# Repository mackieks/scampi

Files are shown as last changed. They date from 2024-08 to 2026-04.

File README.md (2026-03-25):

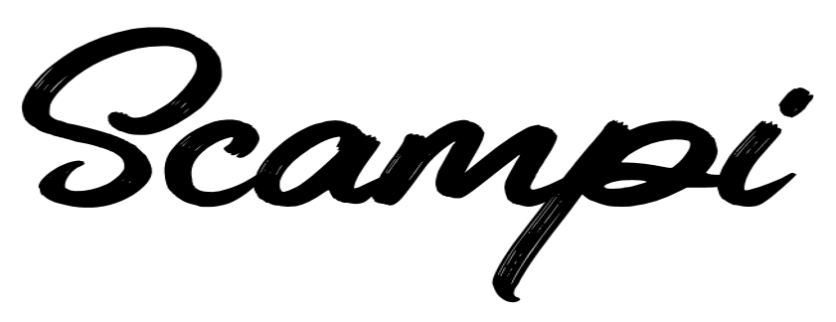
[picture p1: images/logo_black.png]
<picture> <source media="(prefers-color-scheme: dark)" srcset="images/logo.png">  </picture> 

Scampi is a truly universal OSHW audio amp for portablizers. Hardware design is tested and working. Firmware is nearly complete.

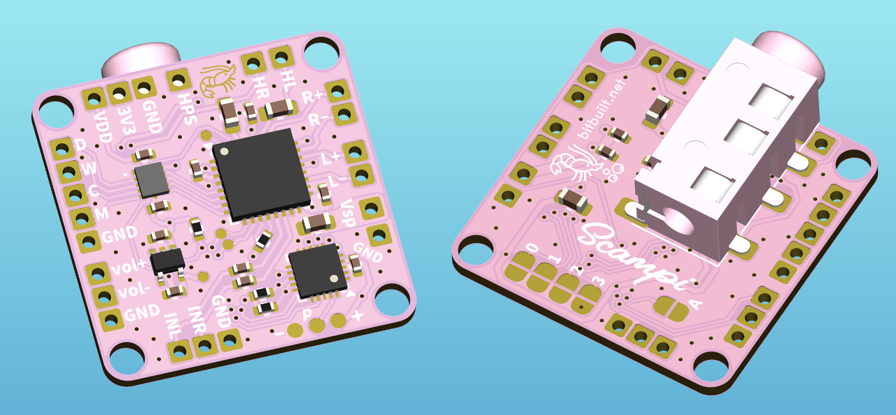
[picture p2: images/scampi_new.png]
 

Features:

- Low-cost 20x20mm 2-layer PCB
- TLV320AIC3110 codec with stereo 1.3W Class-D amps and Class-AB headphone driver
- 5V-tolerant level-shifted I2S input + analog input
- Onboard switching 3.5mm headphone jack
- Solder jumpers for mode selection (15 modes planned)
- Shrimp-themed!🦐
  
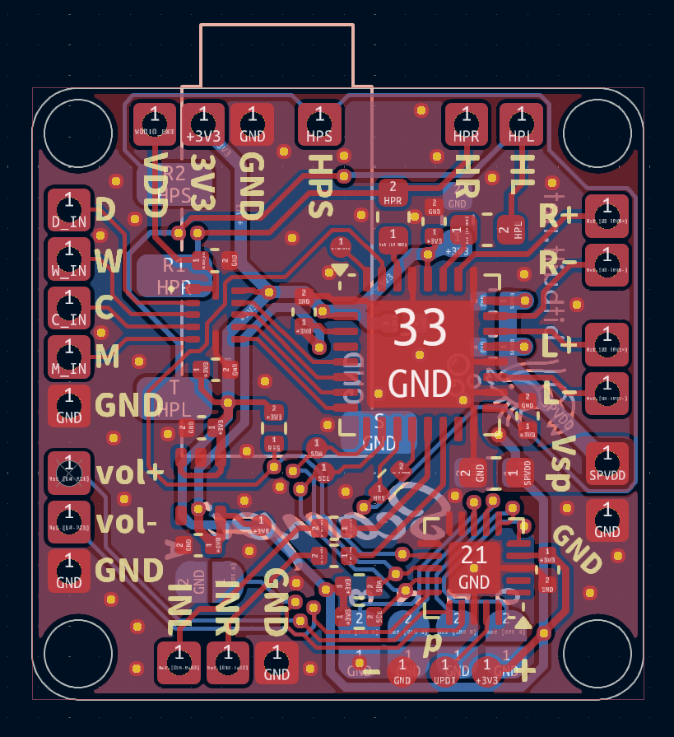
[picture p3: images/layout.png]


Recommended speakers: [Nintendo Switch 2 speakers](https://www.aliexpress.us/item/3256809887996046.html)

Headphone jack (remove pegs with flush cutters): [PJ320D](https://www.aliexpress.us/item/3256808202284065.html)

Hardware tested and working! Firmware is nearly complete! Supported modes so far:

- [x] Analog input
- [x] SNES
- [x] N64
- [x] GameCube
- [x] Wii
- [x] Wii U
- [ ] PS1
- [ ] PS2
- [ ] PS3
- [x] Saturn
- [x] Dreamcast
- [ ] XBOX
- [ ] Xbox 360
- [ ] Jaguar
- [ ] Neo Geo

## License
Solderpad Hardware License v2.1

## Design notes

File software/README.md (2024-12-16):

# Scampi Firmware

Pre-built binaries for the firmware can be found in the [releases](https://github.com/mackieks/scampi/releases) section.

## Firmware

The Scampi firmware is written in AVR C with no external dependencies. It uses [PlatformIO](https://platformio.org/) to build and flash the firmware, providing a consistent build environment and an easy way to manage toolchains.

### Prerequisites

- [PlatformIO IDE](https://platformio.org/install/ide?install=vscode) for VS Code
- UPDI programmer (e.g., [ATMEL-ICE](https://www.microchip.com/en-us/development-tool/atatmel-ice), [Adafruit UPDI Friend](https://www.adafruit.com/product/5879), [SerialUPDI](https://www.tindie.com/products/mcudude/serialupdi-programmer/)).

### Building

To build the firmware in VS Code, open the `firmware` folder in VS Code, and let the PlatformIO extension configure the project. Then click the Build button at the bottom (check mark icon).

### Flashing

Flashing the firmware requires a UPDI programmer. You can use the official [ATMEL-ICE](https://www.microchip.com/en-us/development-tool/atatmel-ice), or a cheaper programmer such as the [Adafruit UPDI Friend](https://www.adafruit.com/product/5879) or MCUdude's [SerialUPDI](https://www.tindie.com/products/mcudude/serialupdi-programmer/).

You need to change line 8 of `platformio.ini` to match the programmer you're using.

- `atmelice_updi` for ATMEL-ICE
- `serialupdi` for SerialUPDI or UPDI Friend

See [this page](https://github.com/SpenceKonde/megaTinyCore/blob/master/megaavr/extras/PlatformIO.md#upload_protocol) for a full list of config options.

The Scampi PCB must be powered from the 3.3V and GND pads for programming to succeed! 

In VS Code, click the Upload button (arrow icon) to flash the firmware. Ensure your UPDI programmer is connected before clicking the button!

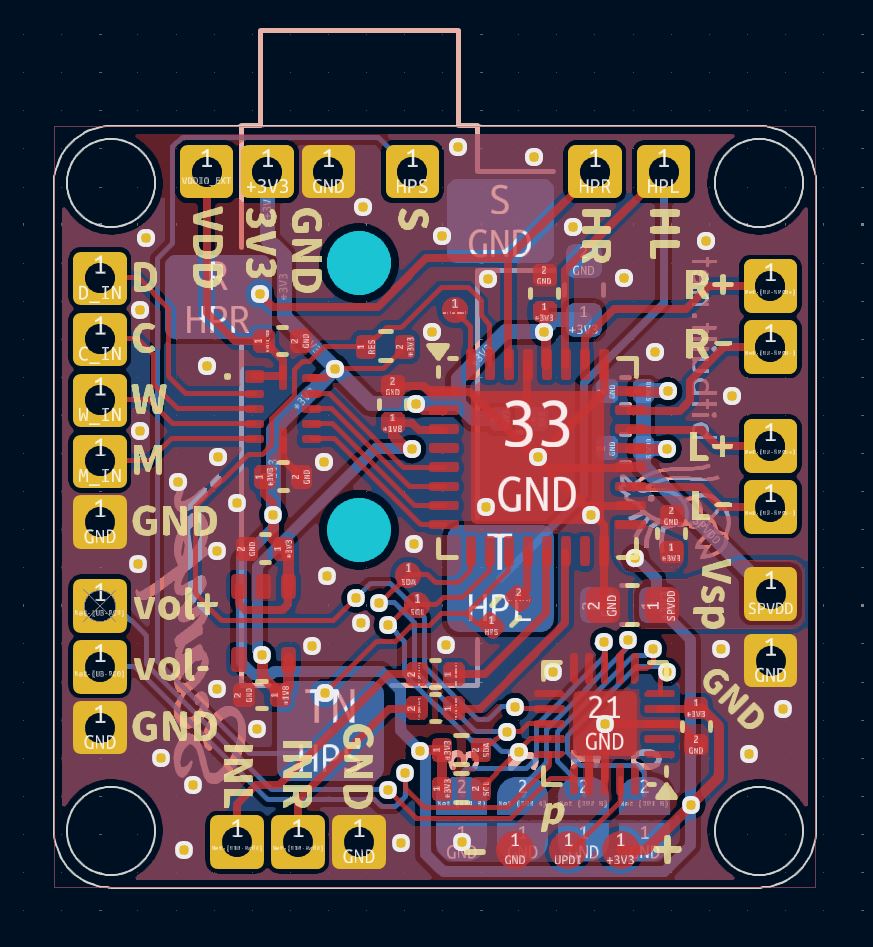
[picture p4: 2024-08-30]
images/layout.jpg

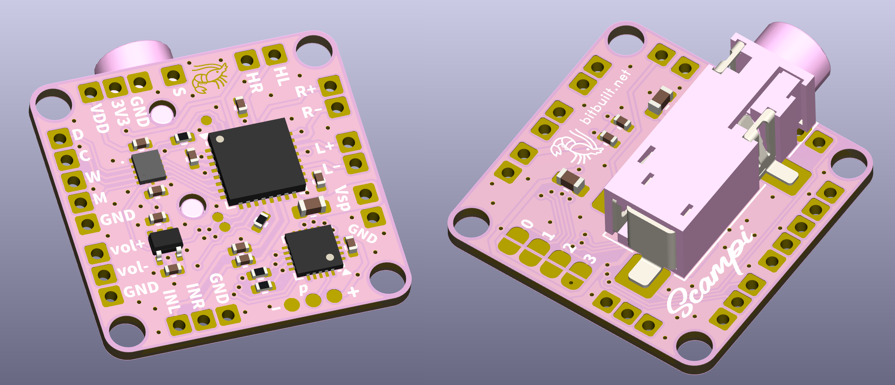
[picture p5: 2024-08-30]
images/scampi.png

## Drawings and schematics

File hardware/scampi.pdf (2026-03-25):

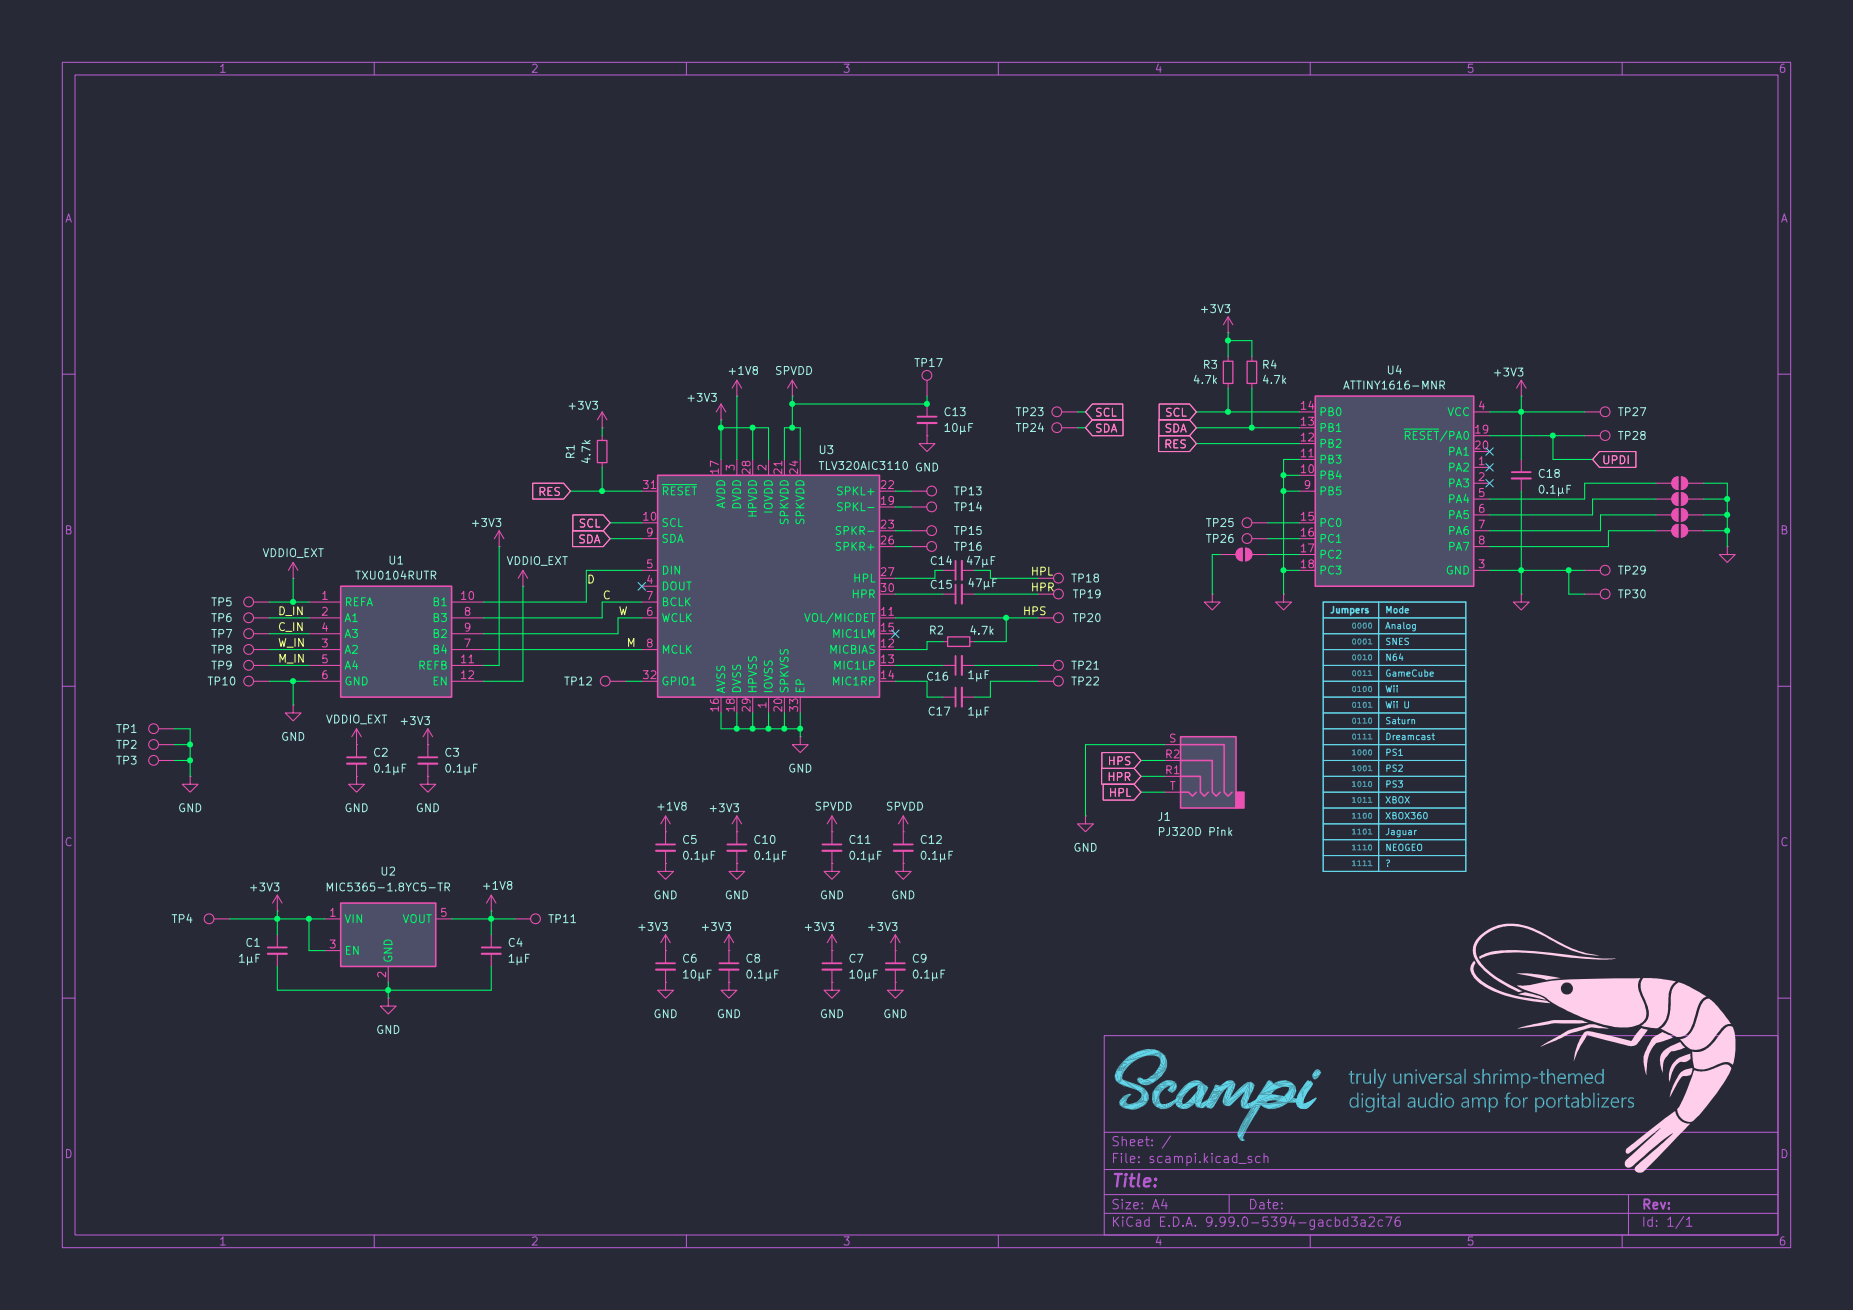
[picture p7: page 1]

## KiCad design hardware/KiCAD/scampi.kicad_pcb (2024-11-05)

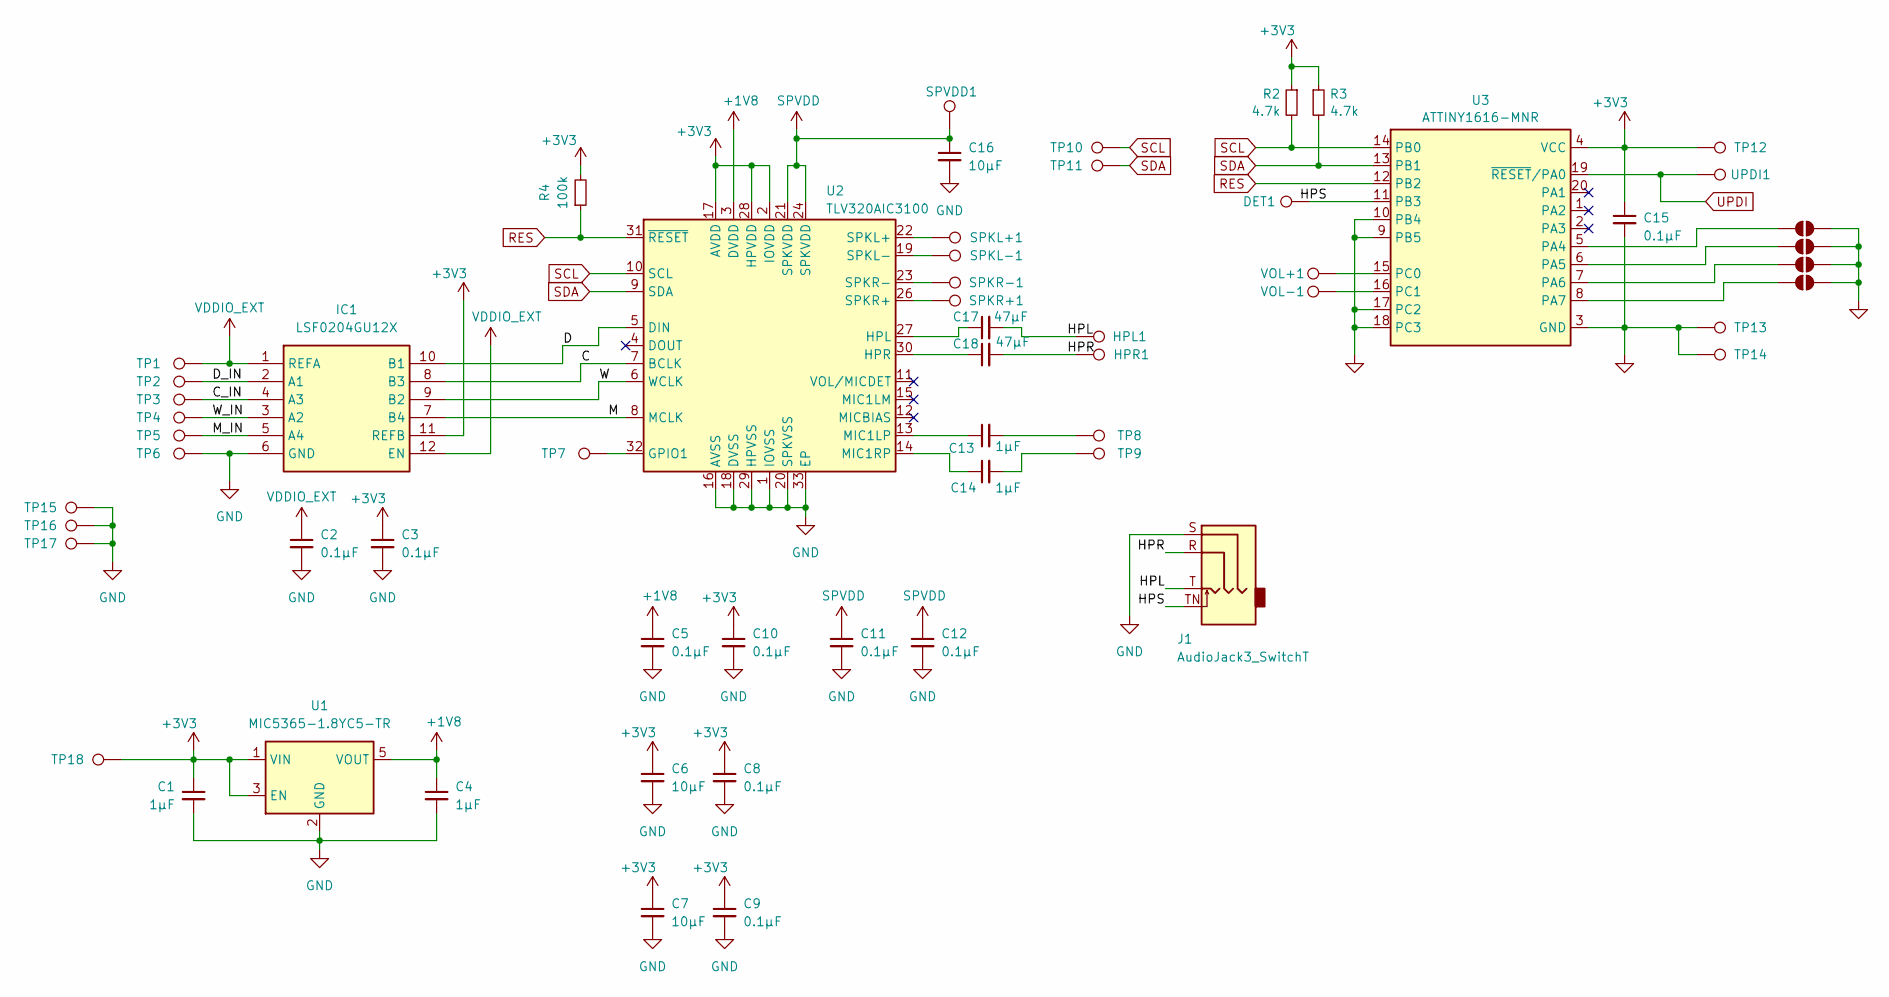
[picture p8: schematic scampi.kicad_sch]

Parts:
C1, C4, C13, C14: 1µF; C_0402_1005Metric
C2, C3, C5, C8, C9, C10, C11, C12, C15: 0.1µF; C_0402_1005Metric
C6, C7, C16: 10µF; C_0603_1608Metric
C17, C18: 47µF; C_0603_1608Metric
DET1: pth_pad
HPL1: pth_pad
HPR1: pth_pad
IC1: LSF0204GU12X; Mouser Part Number 771-LSF0204GU12X
J1: AudioJack3_SwitchT; Jack_3.5mm_CUI_SJ-3524-SMT_Horizontal
JP1, JP2, JP3, JP4: SolderJumper_2_Open; small_solder_jumper
R2, R3: 4.7k; R_0402_1005Metric
R4: 100k; R_0402_1005Metric
SPKL+1: pth_pad
SPKL-1: pth_pad
SPKR+1: pth_pad
SPKR-1: pth_pad
SPVDD1: pth_pad
TP1, TP2, TP3, TP4, TP5, TP6, TP8, TP9, TP15, TP16, TP17, TP18: pth_pad
TP7: TestPoint_Pad_D1.0mm
TP10: SCL; TestPoint_Pad_D1.0mm
TP11: SDA; TestPoint_Pad_D1.0mm
TP12: V+; TestPoint_Pad_D1.0mm
TP13: GND; pth_pad
TP14: GND; TestPoint_Pad_D1.0mm
U1: MIC5365-1.8YC5-TR; SOT-353_SC-70-5
U2: TLV320AIC3100; VQFN-32-1EP_5x5mm_P0.5mm_EP3.5x3.5mm
U3: ATTINY1616-MNR; VQFN-20-1EP_3x3mm_P0.4mm_EP1.7x1.7mm
UPDI1: UPDI; TestPoint_Pad_D1.0mm
VOL+1: pth_pad
VOL-1: pth_pad

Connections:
+1V8: C4.1, C5.1, U1.5 (VOUT), U2.3 (DVDD)
+3V3: C1.1, C3.1, C6.1, C7.1, C8.1, C9.1, C10.1, C15.1, IC1.11 (REFB), R2.1, R3.1, R4.2, TP12.1, TP18.1, U1.1 (VIN), U1.3 (EN), U2.2 (IOVDD), U2.17 (AVDD), U2.28 (HPVDD), U3.4 (VCC)
/C: IC1.8 (B3), U2.7 (BCLK)
/C_IN: IC1.4 (A3), TP3.1
/D: IC1.10 (B1), U2.5 (DIN)
/D_IN: IC1.2 (A1), TP2.1
/HPL: C17.2, HPL1.1, J1.T
/HPR: C18.2, HPR1.1, J1.R
/HPS: DET1.1, J1.TN, U3.11 (PB3)
/M: IC1.7 (B4), U2.8 (MCLK)
/M_IN: IC1.5 (A4), TP5.1
/W: IC1.9 (B2), U2.6 (WCLK)
/W_IN: IC1.3 (A2), TP4.1
GND: C1.2, C2.2, C3.2, C4.2, C5.2, C6.2, C7.2, C8.2, C9.2, C10.2, C11.2, C12.2, C15.2, C16.2, IC1.6 (GND), J1.S, JP1.1 (A), JP2.1 (A), JP3.1 (A), JP4.1 (A), TP6.1, TP13.1, TP14.1, TP15.1, TP16.1, TP17.1, U1.2 (GND), U2.1 (IOVSS), U2.16 (AVSS), U2.18 (DVSS), U2.20 (SPKVSS), U2.25 (SPKVSS), U2.29 (HPVSS), U2.33 (EP), U3.3 (GND), U3.9 (PB5), U3.10 (PB4), U3.17 (PC2), U3.18 (PC3), U3.21 (GND)
unnamed: C13.2, TP8.1
unnamed: C14.2, TP9.1
unnamed: JP1.2 (B), U3.5 (PA4)
unnamed: JP2.2 (B), U3.6 (PA5)
unnamed: JP3.2 (B), U3.7 (PA6)
unnamed: JP4.2 (B), U3.8 (PA7)
unnamed: TP7.1, U2.32 (GPIO1)
unnamed: C17.1, U2.27 (HPL)
unnamed: C18.1, U2.30 (HPR)
unnamed: C13.1, U2.13 (MIC1LP)
unnamed: C14.1, U2.14 (MIC1RP)
unnamed: SPKL+1.1, U2.22 (SPKL+)
unnamed: SPKL-1.1, U2.19 (SPKL-)
unnamed: SPKR+1.1, U2.26 (SPKR+)
unnamed: SPKR-1.1, U2.23 (SPKR-)
unnamed: U3.15 (PC0), VOL+1.1
unnamed: U3.16 (PC1), VOL-1.1
RES: R4.1, U2.31 (~RESET), U3.12 (PB2)
SCL: R2.2, TP10.1, U2.10 (SCL), U3.14 (PB0)
SDA: R3.2, TP11.1, U2.9 (SDA), U3.13 (PB1)
SPVDD: C11.1, C12.1, C16.1, SPVDD1.1, U2.21 (SPKVDD), U2.24 (SPKVDD)
UPDI: U3.19 (~RESET/PA0), UPDI1.1
VDDIO_EXT: C2.1, IC1.1 (REFA), IC1.12 (EN), TP1.1

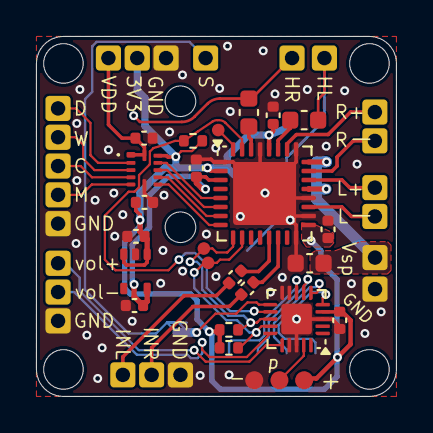
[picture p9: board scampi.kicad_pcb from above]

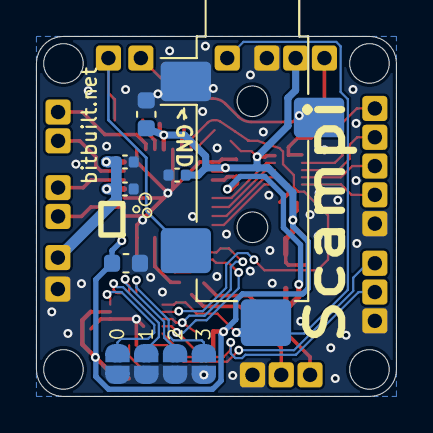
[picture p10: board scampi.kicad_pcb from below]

Board: 2 copper layers, 20.0 x 20.0 mm, 59 parts (10 on the bottom side), 37 nets.

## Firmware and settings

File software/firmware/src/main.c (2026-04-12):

/*
  Scampi firmware

  Application code for ATtiny1616 and TLV320AIC3110

  https://www.ti.com/lit/ds/symlink/tlv320aic3110.pdf

  Mackie Kannard-Smith, James Smith 2024
  MIT License

*/

#include <stdint.h>
#include <string.h>

#include <avr/eeprom.h>
#include <avr/interrupt.h>
#include <avr/io.h>
#include <util/delay.h>

#include "gpio.h"
#include "i2c.h"
#include "i2c/tlv320aic3110.h"

// old PCB has A_MODE tied to GND.
#define FORCE_AMODE 0

// speaker type (controls gain)
#define IPHONE_15PM 0
#define SWITCH_2 1
#define CMS_151135 0
#define FOUR_OHM_20MM 0

// set this to 1 to change the volume pot rotation direction
#define INVERT_VOL_POT 0

// RTC millisecond counter
static volatile uint32_t millis = 0;

static volatile uint8_t mode = 0;

// set this to the min and max ADC readings you get from your volume pot
// for example, if Vmin = 100mV, (0.100 / 3.3) * 1024 = 31
static volatile uint8_t VOL_POT_MIN    = 128; // real value comes from eeprom
static volatile uint8_t VOL_POT_MAX    = 128; // real value comes from eeprom
static volatile uint8_t MUTE_THRESHOLD = 1; // Adjustable threshold above/below POT_MIN/POT_MAX to mute at

static volatile bool analog_vol_ctrl   = 0;
static volatile bool headset_connected = 0;
static volatile bool mute              = 0;
static volatile bool vol_down_pressed  = 0;
static volatile bool vol_up_pressed    = 0;

// higher value = reduced gain (see Table 7-38 in datasheet)
static const uint8_t min_vol = 50;
static const uint8_t max_vol = 0;

#if IPHONE_15PM
static const uint8_t spk_gain = 0x0; // +24dB
#elif SWITCH_2
static const uint8_t spk_gain = 0x0; // +20dB
#elif CMS_151135
static const uint8_t spk_gain = 0x20; // +16dB
#elif FOUR_OHM_20MM
static const uint8_t spk_gain = 0x28; // +20dB
#endif

static const uint8_t hp_gain = 0x00; // 0dB (suitable for my 15Ω headphones)

static volatile uint8_t vol     = 0;
static volatile uint8_t spk_vol = 0;
static volatile uint8_t hp_vol  = 0;

static volatile uint8_t vol_pot = 0; // analog volume pot reading (0 - 255)

// GPIO pin definitions
static const gpio_t RESET  = {&PORTB, 2}; // PB2
static const gpio_t VOL_UP = {&PORTC, 1}; // PC1
static const gpio_t VOL_DN = {&PORTC, 0}; // PC0
static const gpio_t A_MODE = {&PORTC, 2}; // PC2 (analog vol ctrl mode)

static const gpio_t MODE0 = {&PORTA, 4}; // PA4
static const gpio_t MODE1 = {&PORTA, 5}; // PA5
static const gpio_t MODE2 = {&PORTA, 6}; // PA6
static const gpio_t MODE3 = {&PORTA, 7}; // PA7

// Initialize the RTC for periodic interrupts
void rtc_init()
{
  RTC.CLKSEL     = RTC_CLKSEL_INT32K_gc;
  RTC.PITINTCTRL = RTC_PI_bm;
  RTC.PITCTRLA   = RTC_PERIOD_CYC32_gc | RTC_PITEN_bm;
}

// Handle periodic RTC interrupts (every ~1ms)
ISR(RTC_PIT_vect)
{
  // Clear the interrupt flag
  RTC.PITINTFLAGS = RTC_PI_bm;

  // Update the "milliseconds since boot" counter
  millis++;
}

// Force reset eeprom for debug
static void reset_eeprom()
{
  // Write the default pot min and max values
  eeprom_write_byte(0x00, 0x80); // VOL_POT_MIN
  eeprom_write_byte(0x01, 0x80); // VOL_POT_MAX
}

// Initialize the EEPROM if it has never been initialized
static void eeprom_init()
{
  // Return early if the EEPROM has already been initialized
  if (eeprom_read_word(0xFE) == 0xCAFE)
    return;

  // Write the default pot min and max values
  eeprom_write_byte(0x00, 0x80); // VOL_POT_MIN
  eeprom_write_byte(0x01, 0x80); // VOL_POT_MAX

  // Write the signature
  eeprom_write_word(0xFE, 0xCAFE);
}

// Initialize the GPIO pins
static void gpio_init()
{
  // Codec reset, active low
  gpio_output(RESET);
  gpio_set_low(RESET);

  gpio_input(VOL_DN);
  gpio_input(A_MODE);
  gpio_input(MODE0);
  gpio_input(MODE1);
  gpio_input(MODE2);
  gpio_input(MODE3);

  // internal pullups for IO pins

  gpio_pullup(A_MODE);
  gpio_pullup(MODE0);
  gpio_pullup(MODE1);
  gpio_pullup(MODE2);
  gpio_pullup(MODE3);

  if (FORCE_AMODE ? true : !gpio_read(A_MODE)) { // enable analog volume control mode

    analog_vol_ctrl = true;

    // ADC1 on VOL_DN (PC0)
    ADC1.CTRLA   = 0x07; // enable ADC in free-running 8-bit mode
    ADC1.CTRLC   = 0x01010011; // reduced capacitance mode, set VREF to VDD, div16 prescaler
    ADC1.MUXPOS  = ADC_MUXPOS_AIN6_gc; // select PC0
    ADC1.COMMAND = 0b1; // start conversion

    gpio_output(VOL_UP); // use VOL_UP to power the volume pot
    gpio_set_high(VOL_UP);

    // grab VOL_POT_MIN and VOL_POT_MAX from EEPROM
    VOL_POT_MIN = eeprom_read_byte(0x00);
    VOL_POT_MAX = eeprom_read_byte(0x01);

  } else {
    gpio_input(VOL_UP); // use VOL_UP for a button
    gpio_pullup(VOL_UP);
    gpio_pullup(VOL_DN);
  }
}

static uint8_t mode_detect()
{

  mode |= !gpio_read(MODE0);
  mode |= !gpio_read(MODE1) << 1;
  mode |= !gpio_read(MODE2) << 2;
  mode |= !gpio_read(MODE3) << 3;

  return (mode);
}

static void codec_write(int reg, int value)
{ i2c_reg_write_byte(TLV320_ADDR, reg, value); }

volatile int codec_read(int reg)
{
  int data;
  i2c_reg_read_byte(TLV320_ADDR, reg, &data);
  return (data);
}

static void codec_reset()
{
  // Reset codec
  gpio_set_low(RESET);
  _delay_ms(10);
  gpio_set_high(RESET);
}

static void set_dac_gain(uint8_t gain)
{
  // digital gain
  codec_write(0x00, 0x00); // select page 0
  codec_write(0x41, gain); // DAC -> +24dB gain left
  codec_write(0x42, gain); // DAC -> +24dB gain right
}

static void set_spk_vol(uint8_t vol)
{
  codec_write(0x00, 0x01); // Select page 1
  codec_write(0x26, spk_vol); // SPL analog volume
  codec_write(0x27, spk_vol); // SPR analog volume
}

static void set_hp_vol(uint8_t vol)
{
  codec_write(0x00, 0x01); // Select page 1
  codec_write(0x24, hp_vol); // HPL analog volume
  codec_write(0x25, hp_vol); // HPR analog volumee
}

static void mute_spk()
{
  codec_write(0x00, 0x01); // Select page 1
  codec_write(0x2A, 0x00); // SPL driver mute
  codec_write(0x2B, 0x00); // SPR driver mute
  // codec_write(0x20, 0x06); // power down class D drivers
}

static void mute_hp()
{
  codec_write(0x00, 0x01); // Select page 1
  codec_write(0x28, 0x02); // HPL driver mute
  codec_write(0x29, 0x02); // HPR driver mute
  // codec_write(0x1F, 0x04); // power down headphone drivers
}

static void unmute_spk()
{
  codec_write(0x00, 0x01); // Select page 1
  codec_write(0x20, 0xC6); // power up class D drivers

  if (mode == 0) { // analog input mode needs higher SPx driver gain
    codec_write(0x2A, 0b00011100); // SPL driver unmute, +24dB gain
    codec_write(0x2B, 0b00011100); // SPR driver unmute, +24dB gain
  } else { // digital input modes use digital volume control
    codec_write(0x2A, 0b00011100); // SPL driver unmute, +6dB gain
    codec_write(0x2B, 0b00011100); // SPR driver unmute, +6dB gain
  }
}

static void unmute_hp()
{
  codec_write(0x00, 0x01); // Select page 1
  codec_write(0x1F, 0xC4); // power up headphone drivers

  if (mode == 0) { // analog input mode needs higher SPx driver gain
    codec_write(0x28, 0b00101110); // HPL driver unmute, +8dB gain
    codec_write(0x29, 0b00101110); // HPR driver unmute, +8dB gain
  } else { // digital input modes use digital volume control
    codec_write(0x28, 0b00001110); // HPL driver unmute, +2dB gain
    codec_write(0x29, 0b00001110); // HPR driver unmute, +2dB gain
  }
}

static void toggle_mute()
{
  mute = !mute;
  if (mute) {
    if (headset_connected)
      mute_hp();
    else
      mute_spk();
  } else {
    if (headset_connected)
      unmute_hp();
    else
      unmute_spk();
  }
}

/* checks for headphones and handles muting/unmuting */
static void check_headphones()
{
  // headphone detect
  codec_write(0x00, 0x00); // select page 0
  if (codec_read(0x43) & 1 << 5) { // if headset is connected...
    mute_spk();
    set_dac_gain(hp_gain);
    unmute_hp();
    headset_connected = true;
  } else { // if headset is not connected...
    mute_hp();
    set_dac_gain(spk_gain);
    unmute_spk();
    headset_connected = false;
  }
}

/* reads analog volume pot and performs wheel limit calibration */
static void read_pot()
{
  vol_pot = ADC1.RESL;

  // run wheel limit calibration for first 3s after power-on
  if (millis < 5000) {
    if (vol_pot < VOL_POT_MIN) {
      VOL_POT_MIN = vol_pot;
      eeprom_update_byte(0x00, VOL_POT_MIN);
    }
    if (vol_pot > VOL_POT_MAX) {
      VOL_POT_MAX = vol_pot;
      eeprom_update_byte(0x01, VOL_POT_MAX);
    }
  } else {
    // catch miscalibration
    if (vol_pot > VOL_POT_MAX)
      vol_pot = VOL_POT_MAX;
    if (vol_pot < VOL_POT_MIN)
      vol_pot = VOL_POT_MIN;
  }
}

long map(long x, long in_min, long in_max, long out_min, long out_max)
{ return (x - in_min) * (out_max - out_min) / (in_max - in_min) + out_min; }

/* polls volume buttons */
static void check_buttons()
{
  vol_down_pressed = !gpio_read(VOL_DN);
  vol_up_pressed   = !gpio_read(VOL_UP);
}

int main(void)
{
  // Enable prescaler, and set prescaler division to 4 to run at 5MHz
  CPU_CCP           = CCP_IOREG_gc;
  CLKCTRL.MCLKCTRLB = CLKCTRL_PDIV_4X_gc | CLKCTRL_PEN_bm;

  // Enable interrupts
  sei();

  // reset_eeprom for debug
  // reset_eeprom();

  // Initialize eeprom if first boot
  eeprom_init();

  // Initialize the RTC (millis timer)
  rtc_init();

  // Initalize the GPIOs
  gpio_init();

  // Initialize as an I2C controller
  i2c_configure(I2C_MODE_STANDARD);

  codec_reset();

  // Initialize TLV320AIC3110
  codec_write(0x0, 0x0); //  select page 0
  codec_write(0x01, 0x01); // soft reset
  _delay_ms(10);

  // Set TLV320AIC3110 timer to use internal oscillator
  // Required for headphone detection to work without MCLK
  codec_write(0x0, 0x3); //  select page 3
  codec_write(0x10, 0x08); // select internal oscillator

  mode = mode_detect();
  codec_write(0x0, 0x0); //  select page 0

  switch (mode) {

      // SNES, Saturn, Dreamcast, and PS! all work with the same amp config. However, since their digital signal levels
      // are different, I'm keeping separate modes for each console. This lets me dial in the DAC gain for each console
      // without more compile-time flags.

    case 0b0000:
      // analog mode
      codec_write(0x3F, 0b00000010); // power down DACs and disable data paths
      break;

    case 0b0001:

      // SNES mode
      // • 24-bit frame size, 16-bit word size, right-justified
      // • W (WS / LRCLK / FS): 32kHz
      // • C (SCK / BCLK): 1.536MHz (32kHz * 2ch * 24 bit frame size)
      // • M (MCLK): 8.192MHz (256Fs = 256 * 32kHz)

      codec_write(0x04, 0x00); // PLL_CLKIN = MCLK, CODEC_CLKIN = MCLK
      codec_write(0x05, 0x00); // PLL powered off.

      codec_write(0x1B, 0x80); // right justified, 16 bit
      codec_write(0x0B, 0x81); // NDAC is powered and set to 1
      codec_write(0x0C, 0x82); // MDAC is powered and set to 2
      break;

    case 0b0010:
      // N64 mode
      // • 16-bit frame size, 16-bit word size, right-justified
      // • W (WS / LRCLK / FS): 48kHz
      // • C (SCK / BCLK): 1.536MHz (48kHz * 2ch * 16 bit frame size)
      // • no MCLK
      // TODO: apparently the sample rate changes from 32kHz to 22kHz in 1080 Snowboarding 2P mode

      codec_write(0x04, 0b00000111); // PLL_CLKIN = BCLK, CODEC_CLKIN = PLL_CLK
      codec_write(0x05, 0b10010011); // PLL powered up. P = 1, R = 3.
      // J defaults to 4

      codec_write(0x1B, 0x80); // right justified, 16 bit
      codec_write(0x0B, 0x84); // NDAC is powered and set to 4
      codec_write(0x0C, 0x84); // MDAC is powered and set to 4

      // to test (384kHz oversampling)
      // codec_write(0x04, 0b00000111); // PLL_CLKIN = BCLK, CODEC_CLKIN = PLL_CLK
      // codec_write(0x05, 0b10010000); // PLL powered up. P = 1, R = 16
      // // J defaults to 4

      // codec_write(0x1B, 0x80); // right justified, 16 bit
      // codec_write(0x0B, 0x82); // NDAC is powered and set to 2
      // codec_write(0x0C, 0x81); // MDAC is powered and set to 1
      break;

    case 0b0011:
      // GC mode
      // • 16-bit frame size, 16-bit word size, right-justified
      // • W (WS / LRCLK / FS): 48kHz
      // • C (SCK / BCLK): 1.536MHz (48kHz * 2ch * 16 bit frame size)
      // • no MCLK

      codec_write(0x04, 0b00000111); // PLL_CLKIN = BCLK, CODEC_CLKIN = PLL_CLK
      codec_write(0x05, 0b10010010); // PLL powered up. P = 1, R = 2
      codec_write(0x06, 0b00100000); // J = 32 for 2x oversampling

      codec_write(0x1B, 0x80); // right justified, 16 bit
      codec_write(0x0B, 0x84); // NDAC is powered and set to 4
      codec_write(0x0C, 0x82); // MDAC is powered and set to 2
      break;

    case 0b0100:
      // Wii mode
      // • 32-bit frame size, 32-bit word size, left-justified
      // • W (WS / LRCLK / FS): 48kHz
      // • C (SCK / BCLK): 3.072MHz (48kHz * 2ch * 32 bit frame size)
      // • M (MCLK): 12.228MHz (256Fs = 256 * 48kHz)

      codec_write(0x04, 0x00); // PLL_CLKIN = MCLK, CODEC_CLKIN = MCLK
      codec_write(0x05, 0x00); // PLL powered off.

      codec_write(0x1B, 0xF0); // supposed to be left justified 32-bit
      codec_write(0x0B, 0x81); // NDAC is powered and set to 1
      codec_write(0x0C, 0x82); // MDAC is powered and set to 2
      break;

    case 0b0101:
      // Wii U mode
      // • 32-bit frame size, 32-bit word size, left-justified
      // • W (WS / LRCLK / FS): 48kHz
      // • C (SCK / BCLK): 3.072MHz (48kHz * 2ch * 32 bit frame size)
      // • no MCLK

      codec_write(0x04, 0b00000111); // PLL_CLKIN = BCLK, CODEC_CLKIN = PLL_CLK
      codec_write(0x05, 0b10010010); // PLL powered up. P = 1, R = 2
      codec_write(0x06, 0b00010000); // J = 16 for 2x oversampling

      codec_write(0x1B, 0xF0); // supposed to be left justified 32-bit
      codec_write(0x0B, 0x84); // NDAC is powered and set to 4
      codec_write(0x0C, 0x82); // MDAC is powered and set to 2
      break;

    case 0b0110:
      // Saturn mode
      // • 32-bit frame size, 16-bit word size, right-justified
      // • W (WS / LRCLK / FS): 44.1kHz
      // • C (SCK / BCLK): 2.8224MHz (44.1kHz * 2ch * 32 bit frame size)
      // • M (MCLK): 11.2896 (256Fs = 256 * 44.1kHz)

      codec_write(0x04, 0x00); // PLL_CLKIN = MCLK, CODEC_CLKIN = MCLK
      codec_write(0x05, 0x00); // PLL powered off.

      codec_write(0x1B, 0x80); // right justified, 16 bit
      codec_write(0x0B, 0x81); // NDAC is powered and set to 1
      codec_write(0x0C, 0x82); // MDAC is powered and set to 2
      break;

    case 0b0111:
      // Dreamcast mode
      // • 32-bit frame size, 16-bit word size, right-justified
      // • W (WS / LRCLK / FS): 44.1kHz
      // • C (SCK / BCLK): 2.8224MHz (44.1kHz * 2ch * 32 bit frame size)
      // • M (MCLK): 11.2896 (256Fs = 256 * 44.1kHz)

      codec_write(0x04, 0x00); // PLL_CLKIN = MCLK, CODEC_CLKIN = MCLK
      codec_write(0x05, 0x00); // PLL powered off.

      codec_write(0x1B, 0x80); // right justified, 16 bit
      codec_write(0x0B, 0x81); // NDAC is powered and set to 1
      codec_write(0x0C, 0x82); // MDAC is powered and set to 2
      break;

    case 0b1000:
      // PS1 mode
      // • 32-bit frame size, 16-bit word size, right-justified
      // • W (WS / LRCLK / FS): 44.1kHz
      // • C (SCK / BCLK): 2.8224MHz (44.1kHz * 2ch * 32 bit frame size)
      // • M (MCLK): 11.2896 (256Fs = 256 * 44.1kHz)

      codec_write(0x04, 0x00); // PLL_CLKIN = MCLK, CODEC_CLKIN = MCLK
      codec_write(0x05, 0x00); // PLL powered off.

      codec_write(0x1B, 0b10110000); // right justified, 16 bit
      codec_write(0x0B, 0x81); // NDAC is powered and set to 1
      codec_write(0x0C, 0x82); // MDAC is powered and set to 2
      break;

    case 0b1001:
      // PS2 mode
      break;

    case 0b1010:
      // PS3 mode
      break;

    case 0b1011:
      // XBOX mode
      break;

    case 0b1100:
      // XBOX360 mode
      break;

    case 0b1101:
      // Jaguar mode
      break;

    case 0b1110:
      // NEOGEO mode
      // • 24-bit frame size, 16-bit word size, right-justified
      // • W (WS / LRCLK / FS): 55.56kHz
      // • C (SCK / BCLK): 2.667MHz (55.56kHz * 2ch * 24 bit frame size)
      // • no MCLK

      codec_write(0x04, 0b00000111); // PLL_CLKIN = BCLK, CODEC_CLKIN = PLL_CLK
      codec_write(0x05, 0b10010011); // PLL powered up. P = 1, R = 3.
      // J defaults to 4

      codec_write(0x1B, 0x80); // right justified, 16 bit
      codec_write(0x0B, 0x84); // NDAC is powered and set to 4
      codec_write(0x0C, 0x84); // MDAC is powered and set to 4

      break;
      break;

    case 0b1111:
      // ????
      break;

    default:
      // ????
      break;
  }

  // finish up amp init

  if (mode == 0) { // analog mode
    codec_write(0x00, 0x01); // Select page 1
    codec_write(0x23, 0b00100010); // analog inputs routed to mixers

  } else { // digital modes
    codec_write(0x74, 0x00); // DAC -> volume control pin disable
    codec_write(0x44, 0x00); // DAC -> DRC disable

    codec_write(0x00, 0x01); // Select page 1

    codec_write(0x23, 0x44); // DAC outputs routed to mixers

    codec_write(0x00, 0x00); // select page 0

    codec_write(0x3F, 0xD6); // power up DACs and enable data paths
    codec_write(0x40, 0x00); // unmute DAC left and right channels
  }

  codec_write(0x00, 0x01); // Select page 1
  codec_write(0x21, 0x4E); // De-pop, power on = 800 ms, step time = 4ms

  set_hp_vol(hp_vol);
  set_spk_vol(spk_vol);

  // mute everything at first
  mute_hp();
  mute_spk();

  codec_write(0x2E, 0x0B); // Micbias set to AVDD (for HPS pull-up)

  codec_write(0x00, 0x00); // select page 0

  codec_write(0x43, 0x93); // headset detection enabled

  check_headphones();

  // Main loop
  while (1) {

    if (!mute)
      check_headphones();

    if (analog_vol_ctrl) {
      // read analog volume wheel
      read_pot();

      // mute if value is beyond threshold
      if (INVERT_VOL_POT ? vol_pot < (VOL_POT_MIN + MUTE_THRESHOLD) 
                         : vol_pot > (VOL_POT_MAX - MUTE_THRESHOLD)) {
        mute = true;
        if (headset_connected)
          mute_hp();
        else
          mute_spk();
      } else {
        mute = false;
        if (headset_connected)
          unmute_hp();
        else
          unmute_spk();
        // map ADC value to volume
        // 2. Handle inversion logic
        if (INVERT_VOL_POT) {
          vol = map(vol_pot, VOL_POT_MIN + MUTE_THRESHOLD, VOL_POT_MAX, min_vol, max_vol);
        } else {
          vol = map(vol_pot, VOL_POT_MIN, VOL_POT_MAX - MUTE_THRESHOLD, max_vol, min_vol);
        }

        // handle volume change
        if (!mute) {
          if (headset_connected) {
            hp_vol = vol;
            set_hp_vol(hp_vol);
          } else {
            spk_vol = vol;
            set_spk_vol(spk_vol);
          }
        }
      }
    } else { // digital volume control
      check_buttons();
      if (vol_down_pressed) {
        if (vol_up_pressed) { // both vol buttons pressed. MUTE/UNMUTE
          toggle_mute();
          _delay_ms(50);
          while (vol_down_pressed && vol_up_pressed) { check_buttons(); } // wait for buttons to be released
        } else { // decrease volume
          if (!mute) {
            if (headset_connected) {
              if (hp_vol < min_vol) {
                hp_vol += 2;
                set_hp_vol(hp_vol);
              }
            } else {
              if (spk_vol < min_vol) {
                spk_vol += 2;
                set_spk_vol(spk_vol);
              }
            }
          }
        }

      } else if (vol_up_pressed) {
        if (vol_down_pressed) { // both vol buttons pressed. MUTE/UNMUTE
          toggle_mute();
          _delay_ms(50);
          while (vol_down_pressed && vol_up_pressed) { check_buttons(); } // wait for buttons to be released
        } else { // increase volume
          if (!mute) {
            if (headset_connected) {
              if (hp_vol > max_vol) {
                hp_vol -= 2;
                set_hp_vol(hp_vol);
              }
            } else {
              if (spk_vol > max_vol) {
                spk_vol -= 2;
                set_spk_vol(spk_vol);
              }
            }
          }
        }
      }
    }

    // in analog volume control mode, we want to sample again ASAP
    if (!analog_vol_ctrl) {
      _delay_ms(50);
    }
  }
}

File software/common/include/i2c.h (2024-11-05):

/**
 * Cross platform I2C library, heavily inspired by the Linux/Zephyr I2C APIs.
 *
 * Provides functions for configuring the I2C bus, sending messages, and reading/writing registers.
 *
 * It is up to the platform to implement both the `i2c_configure` and `i2c_transfer` functions.
 */

#pragma once

#include <stdbool.h>
#include <stdint.h>

/**
 * I2C modes.
 */

/** Standard mode (100 KHz) */
#define I2C_MODE_STANDARD       0

/** Fast mode (400 KHz) */
#define I2C_MODE_FAST           1

/**
 * I2C message flags.
 */

/** Write message to the I2C bus. */
#define I2C_MSG_WRITE           (0 << 0)

/** Read message from the I2C bus. */
#define I2C_MSG_READ            (1 << 0)

/** Send a STOP condition after the message. */
#define I2C_MSG_STOP            (1 << 1)

/** Send a RESTART condition before this message. */
#define I2C_MSG_RESTART         (1 << 2)

/**
 * A message to be sent or received on the I2C bus.
 */
struct i2c_msg {
  /** Data buffer */
  uint8_t *buf;

  /** Length of the buffer, in bytes */
  uint32_t len;

  /** Flags for the message */
  uint8_t flags;
};

/**
 * I2C error codes.
 */
enum i2c_error {
  I2C_ERR = 1,
};

/**
 * Initialize the I2C bus as a controller.
 *
 * @param mode I2C_MODE_STANDARD or I2C_MODE_FAST
 * @return 0 if successful, negative error code
 */
int i2c_configure(uint8_t mode);

/**
 * Send one or more messages on the I2C bus, in a single transfer.
 * STOP is issued to terminate the operation; each message begins with a START.
 *
 * @param addr     7-bit I2C address
 * @param msgs     Array of messages to send
 * @param num_msgs Number of messages to send
 * @return 0 if successful, negative error code otherwise
 */
int i2c_transfer(uint8_t addr, struct i2c_msg *msgs, uint8_t num_msgs);

/**
 * Detect if an I2C device is present at a given address.
 *
 * @param addr 7-bit I2C address of the target device
 * @return true if the device is present, false otherwise
 */
static inline bool i2c_detect(uint8_t addr)
{
  uint8_t tmp;

  struct i2c_msg msg = {
      .buf   = &tmp,
      .len   = 0,
      .flags = I2C_MSG_WRITE | I2C_MSG_STOP,
  };

  return i2c_transfer(addr, &msg, 1) == 0;
}

/**
 * Write a set amount of data to an I2C device.
 *
 * @param addr 7-bit I2C address of the target device
 * @param buf Buffer containing the data to write
 * @param len Number of bytes to write
 * @return 0 if successful, negative error code otherwise
 */
static inline int i2c_write(uint8_t addr, uint8_t *buf, uint32_t len)
{
  struct i2c_msg msg = {
      .buf   = buf,
      .len   = len,
      .flags = I2C_MSG_WRITE | I2C_MSG_STOP,
  };

  return i2c_transfer(addr, &msg, 1);
}

/**
 * Read a set amount of data from an I2C device.
 *
 * @param addr 7-bit I2C address of the target device
 * @param buf Buffer to store the read data
 * @param len Number of bytes to read
 *
 * @return 0 if successful, negative error code otherwise
 */
static inline int i2c_read(uint8_t addr, uint8_t *buf, uint32_t len)
{
  struct i2c_msg msg = {
      .buf   = buf,
      .len   = len,
      .flags = I2C_MSG_READ | I2C_MSG_STOP,
  };

  return i2c_transfer(addr, &msg, 1);
}

/**
 * Write then read from an I2C device.
 *
 * @param addr 7-bit I2C address of the target device
 * @param write_buf Buffer to write to the device
 * @param write_len Length of the write buffer
 * @param read_buf Buffer to read from the device
 * @param read_len Length of the read buffer
 */
static inline int i2c_write_read(uint8_t addr, uint8_t *write_buf, uint32_t write_len, uint8_t *read_buf,
                                 uint32_t read_len)
{
  struct i2c_msg msgs[] = {
      {
          .buf   = write_buf,
          .len   = write_len,
          .flags = I2C_MSG_WRITE,
      },
      {
          .buf   = read_buf,
          .len   = read_len,
          .flags = I2C_MSG_RESTART | I2C_MSG_READ | I2C_MSG_STOP,
      },
  };

  return i2c_transfer(addr, msgs, 2);
}

/**
 * Read a single byte from an I2C device, at the specified register address.
 * This is identical to the SMBus "Read Byte" command.
 *
 * @param addr 7-bit I2C address of the target device
 * @param reg Register address to read from
 * @param data Pointer to store the read data
 * @return 0 if successful, negative error code otherwise
 */
static inline int i2c_reg_read_byte(uint8_t addr, uint8_t reg, uint8_t *data)
{
  return i2c_write_read(addr, &reg, 1, data, 1);
}

/**
 * Write a single byte to an I2C device, at the specified register address.
 * This is identical to the SMBus "Write Byte" command.
 *
 * @param addr 7-bit I2C address of the target device
 * @param reg Register address to write to
 * @param value Value to write to the register
 * @return 0 if successful, negative error code otherwise
 */
static inline int i2c_reg_write_byte(uint8_t addr, uint8_t reg, uint8_t value)
{
  uint8_t buf[] = {reg, value};
  return i2c_write(addr, buf, 2);
}

/**
 * Read a little-endian word from an I2C device, at the specified register address.
 * This is identical to the SMBus "Read Word" command.
 *
 * @param addr 7-bit I2C address of the target device
 * @param reg Register address to read from
 * @param value Pointer to store the read data
 * @return 0 if successful, negative error code otherwise
 */
static inline int i2c_reg_read_word(uint8_t addr, uint8_t reg, uint16_t *value)
{
  int rcode;

  // Read the register value
  uint8_t buf[2];
  if ((rcode = i2c_write_read(addr, &reg, 1, buf, 2)) < 0)
    return rcode;

  // Combine the two bytes into a little-endian word
  *value = buf[0] | (buf[1] << 8);

  return 0;
}

/**
 * Write a little-endian word to an I2C device, at the specified register address.
 * This is identical to the SMBus "Write Word" command.
 *
 * @param addr 7-bit I2C address of the target device
 * @param reg Register address to write to
 * @param value Value to write to the register
 * @return 0 if successful, negative error code otherwise
 */
static inline int i2c_reg_write_word(uint8_t addr, uint8_t reg, uint16_t value)
{
  uint8_t buf[] = {reg, value & 0xFF, value >> 8};
  return i2c_write(addr, buf, 3);
}

/**
 * Perform a read/modify/write operation on a single byte register of an I2C device.
 *
 * @param addr 7-bit I2C address of the target device
 * @param reg Register address to read from and write to
 * @param mask Bitmask to apply to the register value
 * @param value Value to write to the register
 * @return 0 if successful, negative error code otherwise
 */
static inline int i2c_reg_update_byte(uint8_t addr, uint8_t reg, uint8_t mask, uint8_t value)
{
  int rcode;

  // Read the current register value
  uint8_t old_value;
  if ((rcode = i2c_reg_read_byte(addr, reg, &old_value)) < 0)
    return rcode;

  // Update the register value
  uint8_t new_value = (old_value & ~mask) | (value & mask);
  if (new_value == old_value) {
    return 0;
  }

  // Write the updated register value
  return i2c_reg_write_byte(addr, reg, new_value);
}

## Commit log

2024-08-30 Add gerbers
    [scampi-B_Cu.gbr, scampi-B_Mask.gbr, scampi-B_Silkscreen.gbr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]
2024-08-31 add ibom and jig
    [scampi_jig-B_Cu.gbr, scampi_jig-B_Mask.gbr, scampi_jig-B_Silkscreen.gbr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]
2024-09-10 board tweaks & firmware
    [scampi-B_Cu.gbr, scampi-B_Mask.gbr, scampi-B_Silkscreen.gbr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]
2024-11-05 firmware, new layout
    [scampi.kicad_pcb, scampi.kicad_sch]
2024-11-05 layout changes, ADC test fw
    [scampi.kicad_pcb, scampi.kicad_sch]
2024-11-06 finalize layout, add gerbers and step file
    [scampi-B_Cu.gbr, scampi-B_Mask.gbr, scampi-B_Paste.gbr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]
2024-11-15 finalize layout!
    [scampi-B_Cu.gbr, scampi-B_Mask.gbr, scampi-B_Paste.gbr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]
2025-02-02 add bom, embed fonts + 3d
    [scampi.kicad_sch]
2025-02-02 clean up
    [scampi-B_Cu.gbr, scampi-B_Mask.gbr, scampi-B_Paste.gbr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]
2026-03-19 Update main.c
    flesh out analog volume wheel. add automatic wheel limit calibration
2026-03-19 Update main.c
    Fix headphone detection
    [main.c]
2026-03-20 Analog input mode + volume fixes
    - add working analog input mode
    - add switch 2 speaker gain
    - adjusted spk/hp volume in analog and digital input modes
    [main.c]
2026-03-25 Add schematic pdf
    [scampi.kicad_sch]
2026-03-25 organize schematic and STEP files
2026-03-25 Update schematic
    [scampi.kicad_sch]
2026-03-25 Update BOM
2026-03-25 update schematic pdf
